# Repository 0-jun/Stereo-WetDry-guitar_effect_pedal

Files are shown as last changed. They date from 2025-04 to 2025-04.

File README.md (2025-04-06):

Stereo Wet/Dry pedal
=======================
The effect pedal has the following functions.
* Dry_In : Split dry signal to sum into each channel of the stereo wet signal
* Dry_Buffered_Bypass (DBD) : Output buffered dry signal for using input of another pedal
* Wet_Right_In (WR In), Wet_Left_In (WL In) : Stereo input for signals such as delay, reverb, chorus, etc
* WRD_Out, WLD_Out : Output stereo of wet+dry signal (or you can use it as a mono using only one channel)
* Four volume knob : Set the volume of two dry signals and two wet signals by knob

## PCB
I divided the pcb into three to put all parts in the pedal case.
1. power part
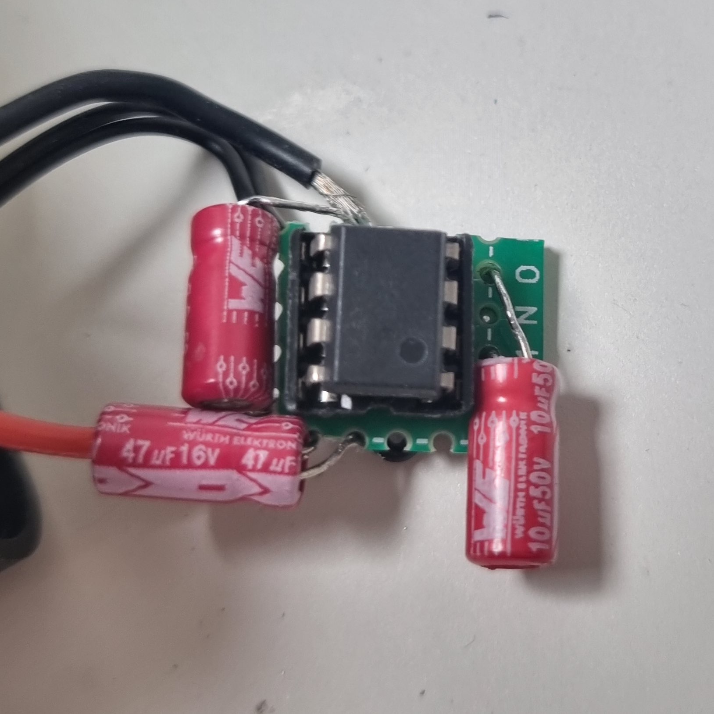
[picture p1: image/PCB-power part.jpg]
PCB-power part

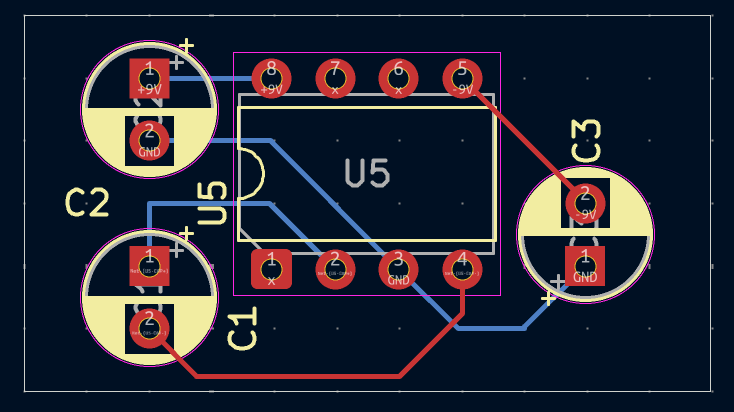
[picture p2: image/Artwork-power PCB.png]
Artwork-power part

2. register for half vdd inputa
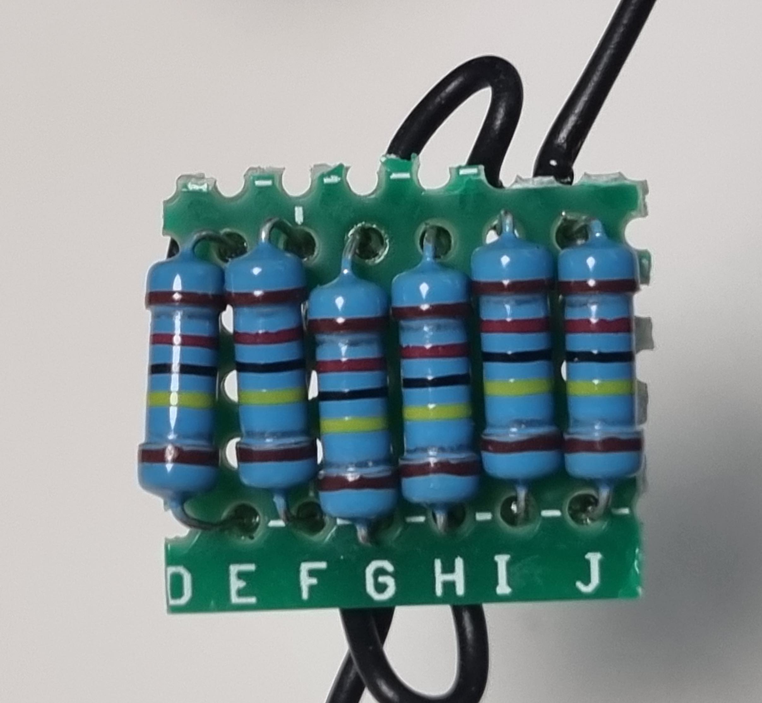
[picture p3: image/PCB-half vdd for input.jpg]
PCB-half vdd for input part

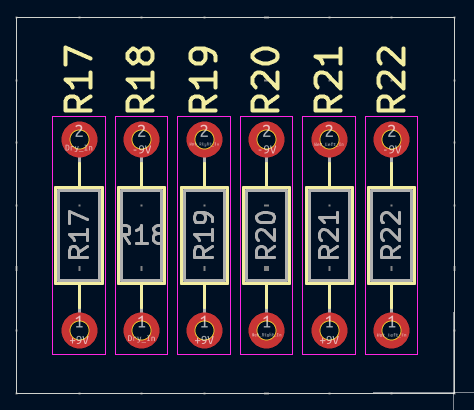
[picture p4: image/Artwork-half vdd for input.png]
Artwork-half vdd for input part

3. main part (opamp)
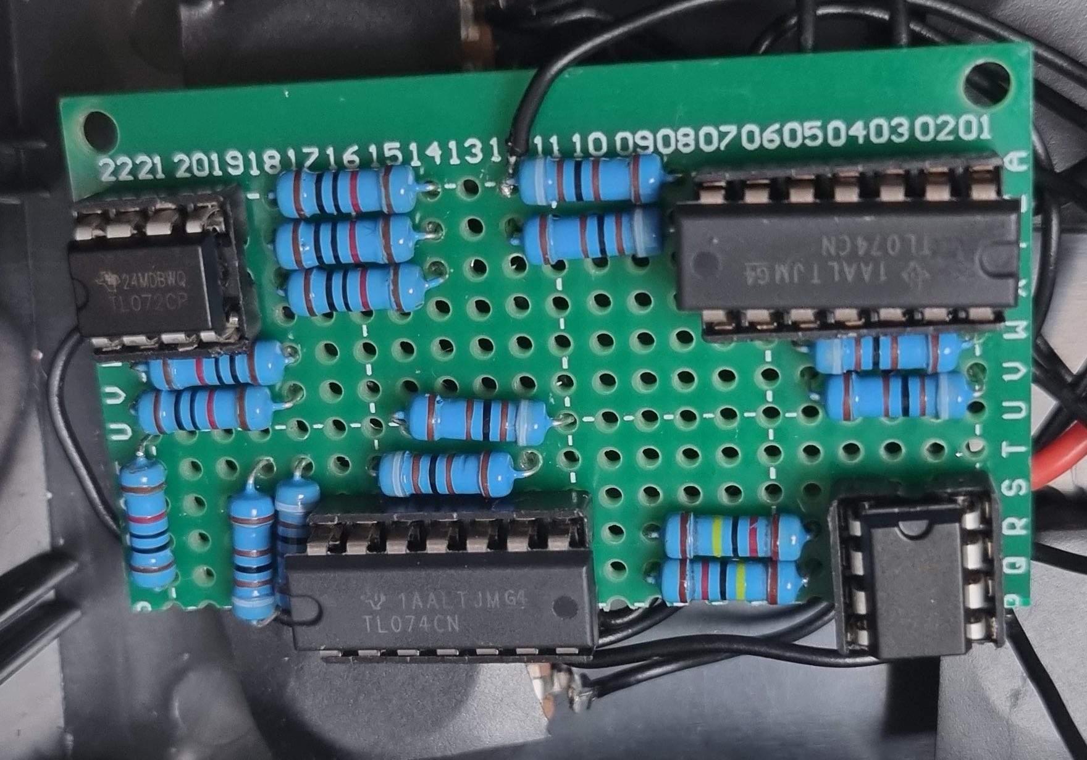
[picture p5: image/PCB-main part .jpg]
PCB-main part

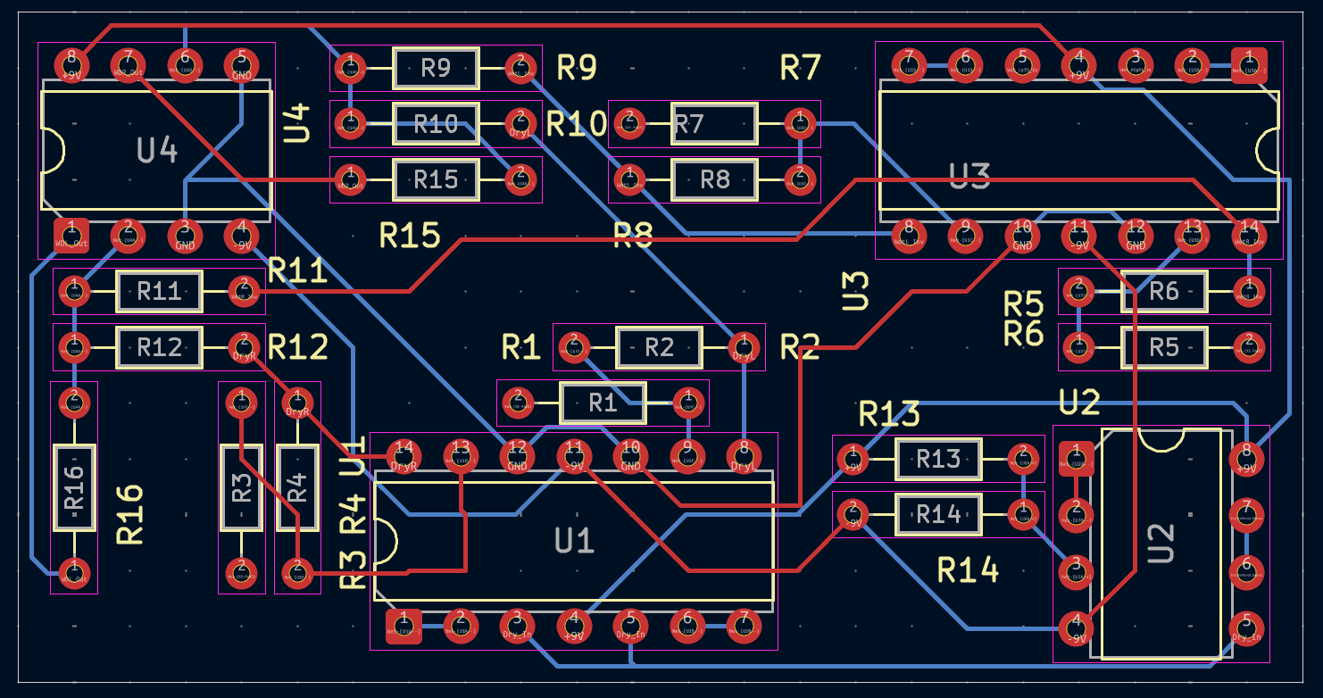
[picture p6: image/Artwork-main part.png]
Artwork-main part


## Verify signal
1.Verify Dry_In (triangle wave) signal and Dry_Buffered_Bypass
 * blue signal : Dry_In (STM32 DAC out (triangle wave))
 * yellow signal : Dry_Buffered_Bypass
Dry_In and Dry_Buffered_Bypass
2. Verify Dry_In signal (triangle wave) and WRD_Out signal (guitar signal) mixed
 * blue signal : Dry_In (STM32 DAC out (triangle wave))
 * yellow signal : WRD_Out (blue signal + guitar signal)
Mixed signal

## Conclusion
It was confirmed that the dry signal and the wet signal were mixed when connected in the following configuration.\
Also, it can be used channel2 of U2(OPAMP) for Dry_Buffered_Byass2.

### configuration
* config1
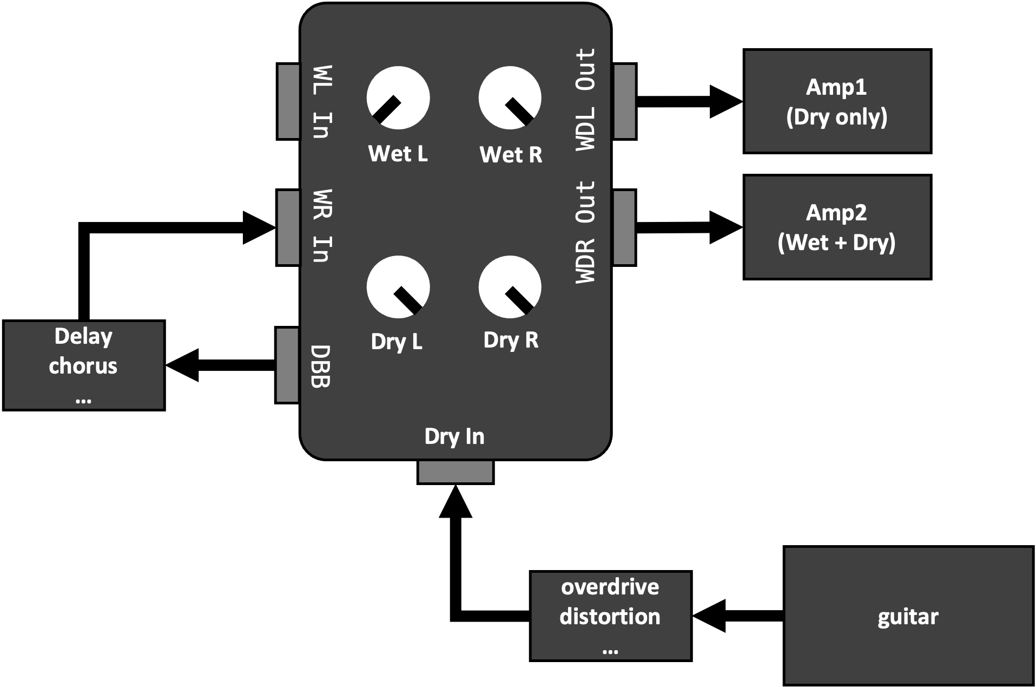
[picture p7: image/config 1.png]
config1

* config2
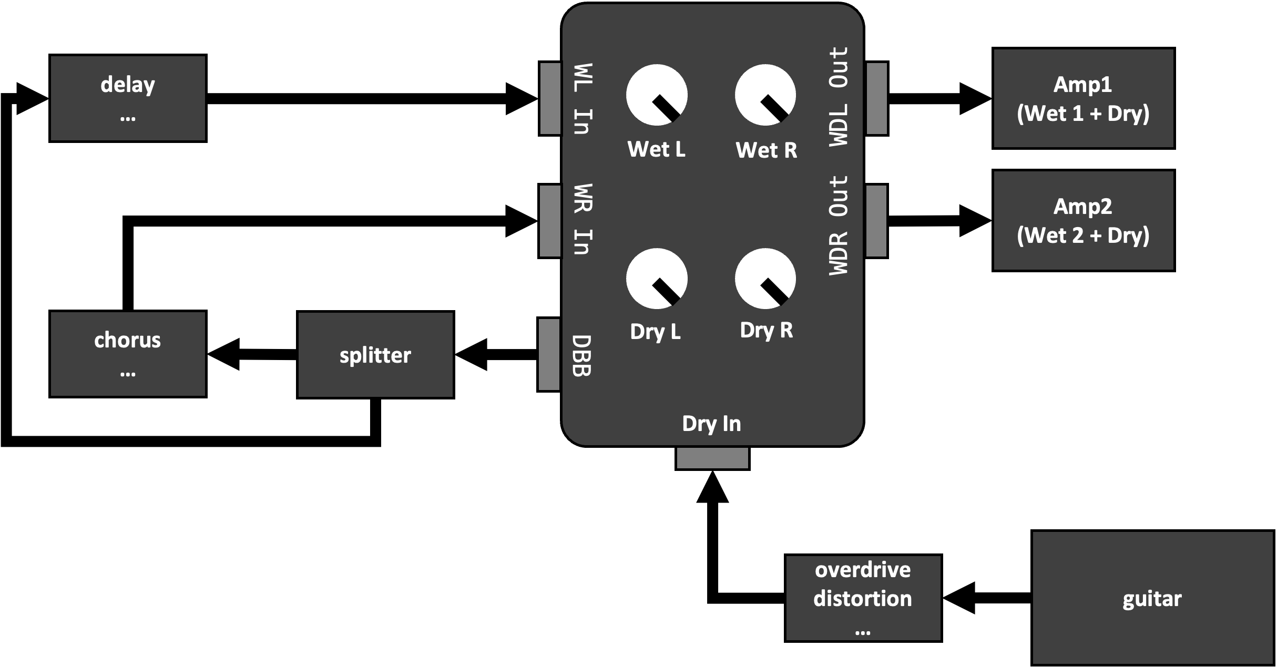
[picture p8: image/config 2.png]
config2

* config3
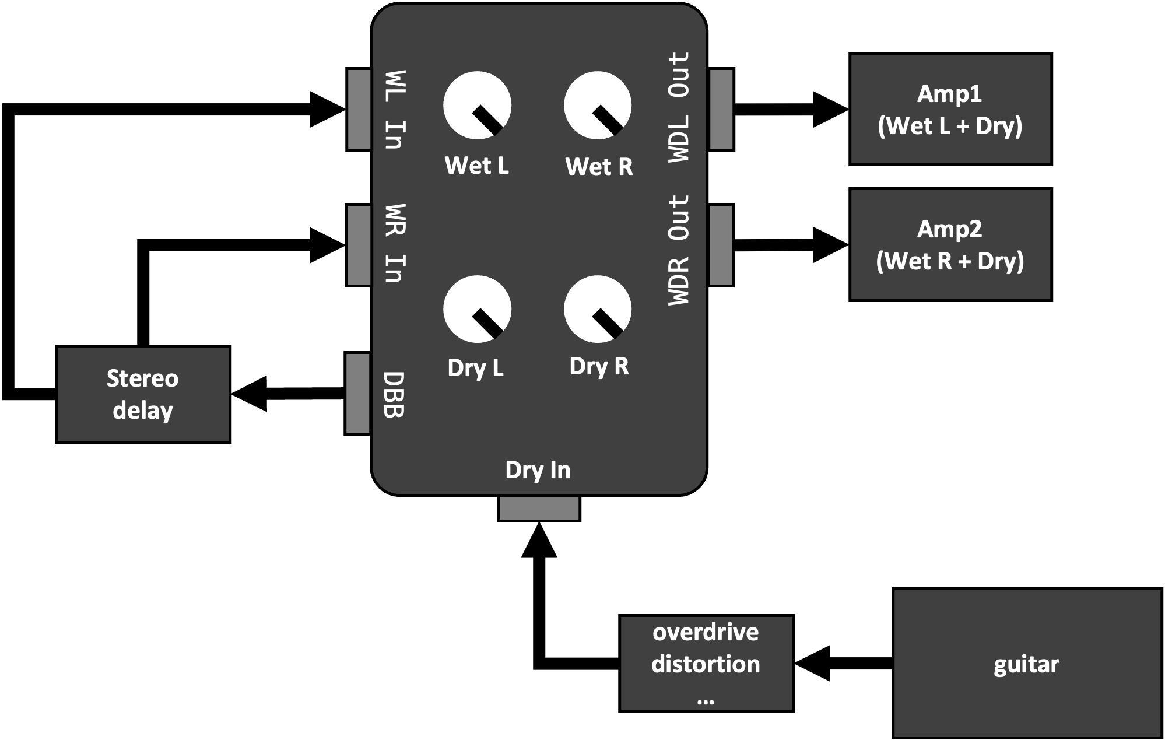
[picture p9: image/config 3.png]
config3


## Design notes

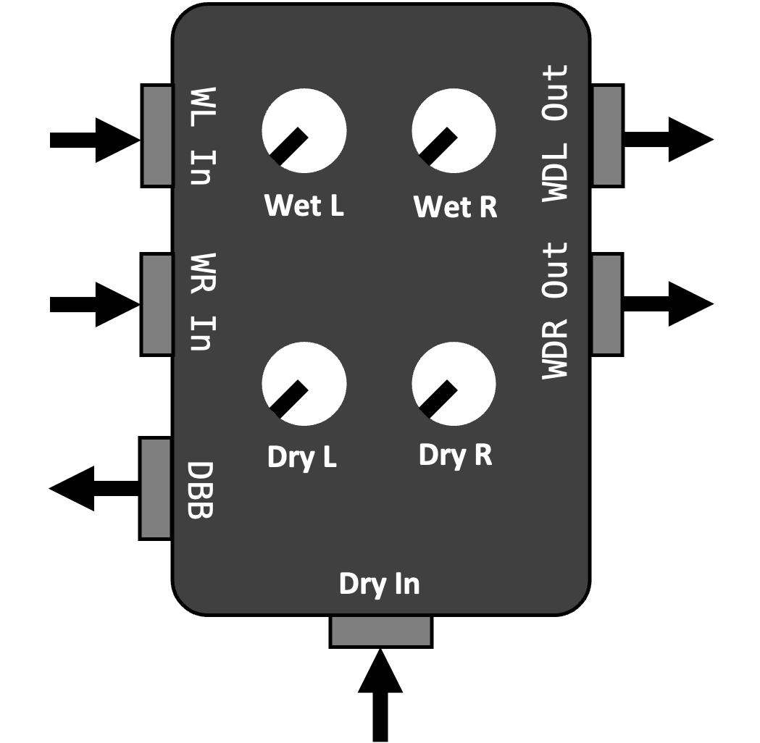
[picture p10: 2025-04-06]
image/pedal.png

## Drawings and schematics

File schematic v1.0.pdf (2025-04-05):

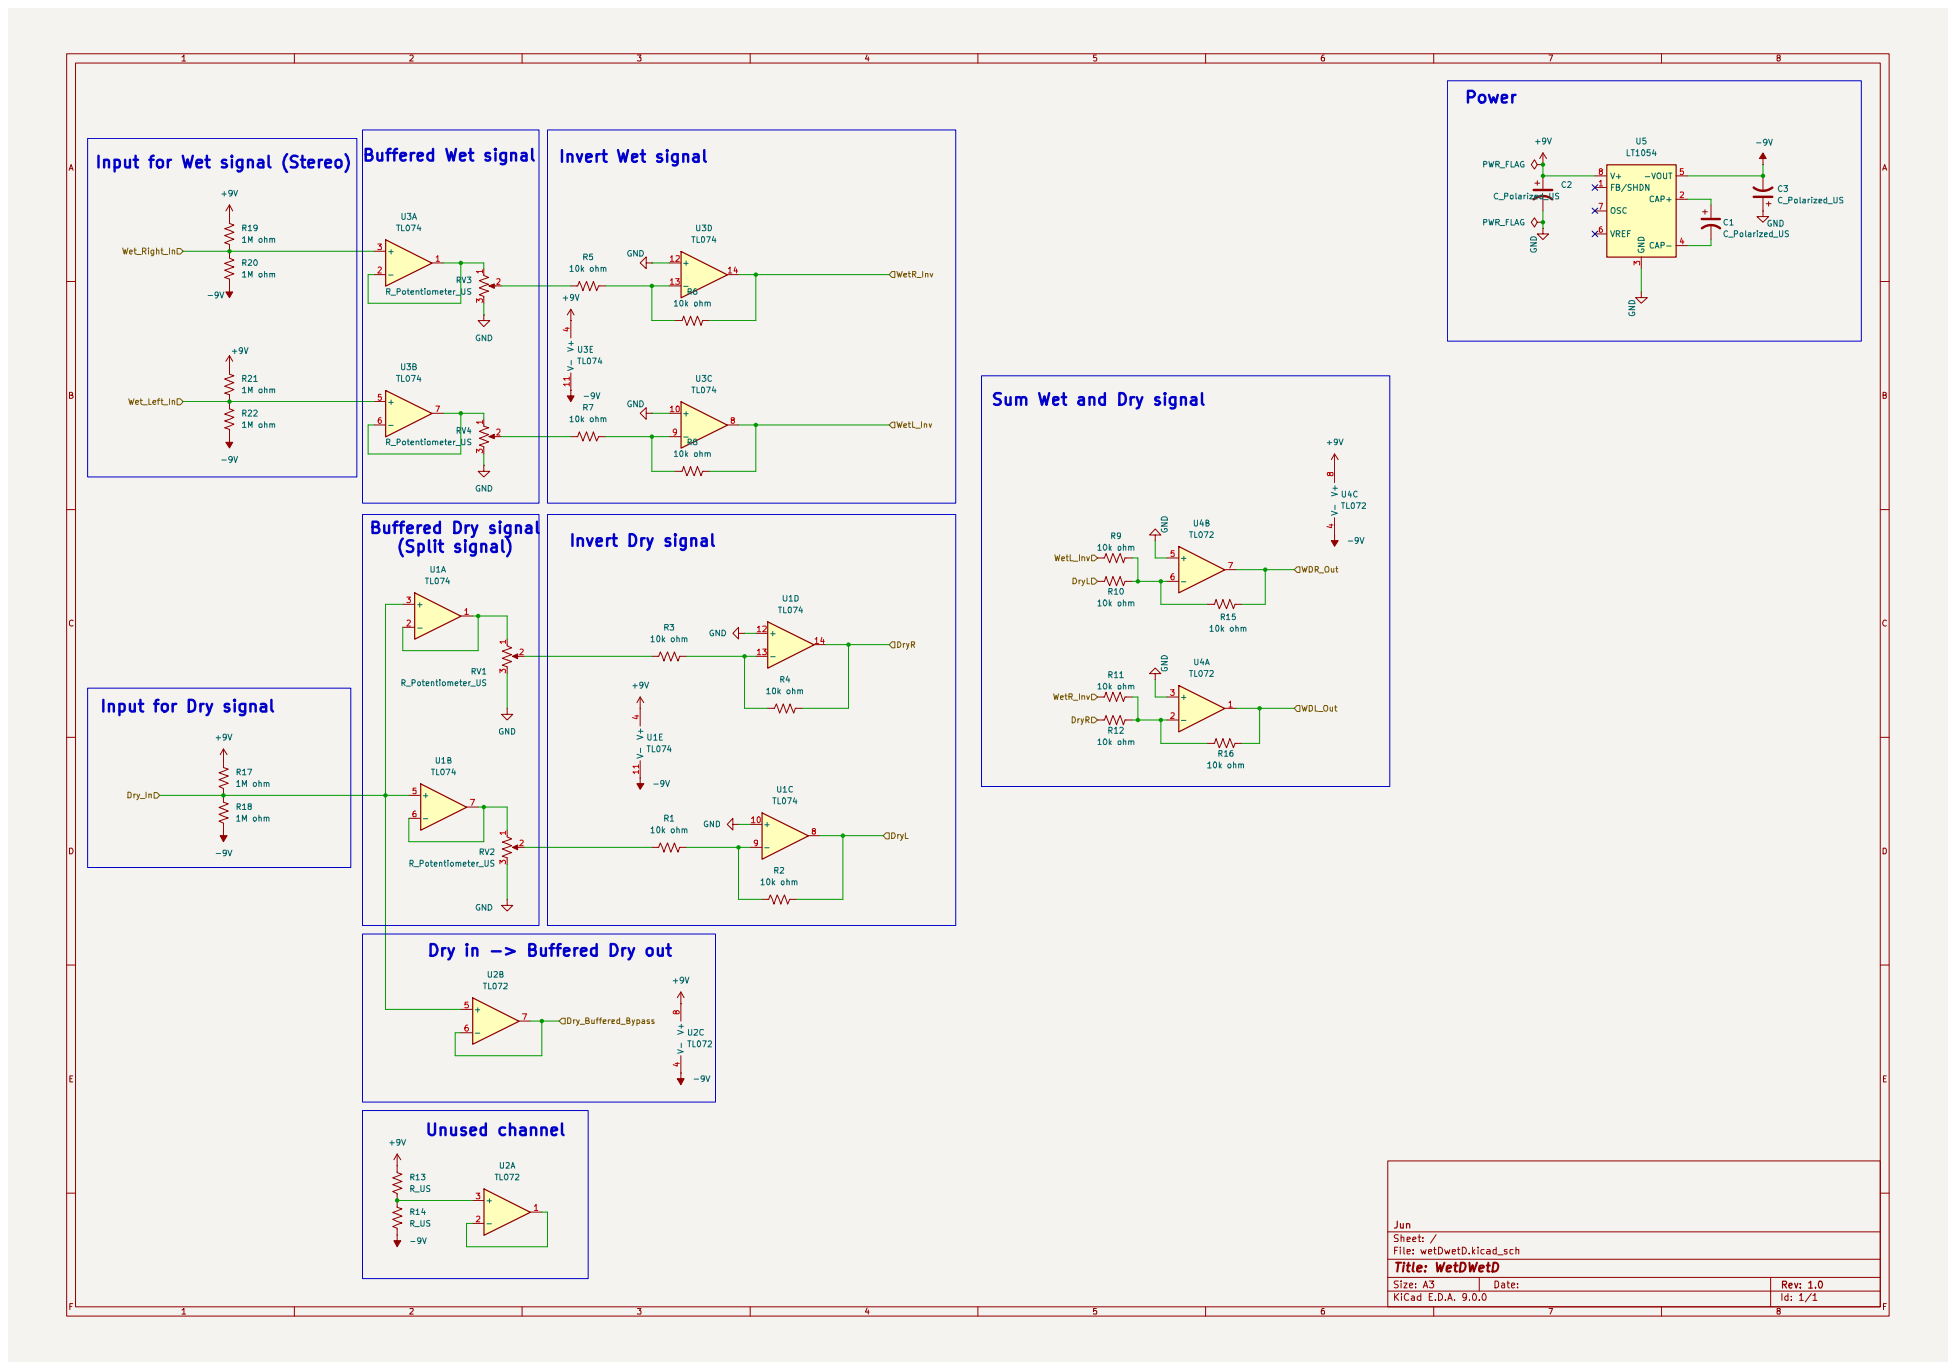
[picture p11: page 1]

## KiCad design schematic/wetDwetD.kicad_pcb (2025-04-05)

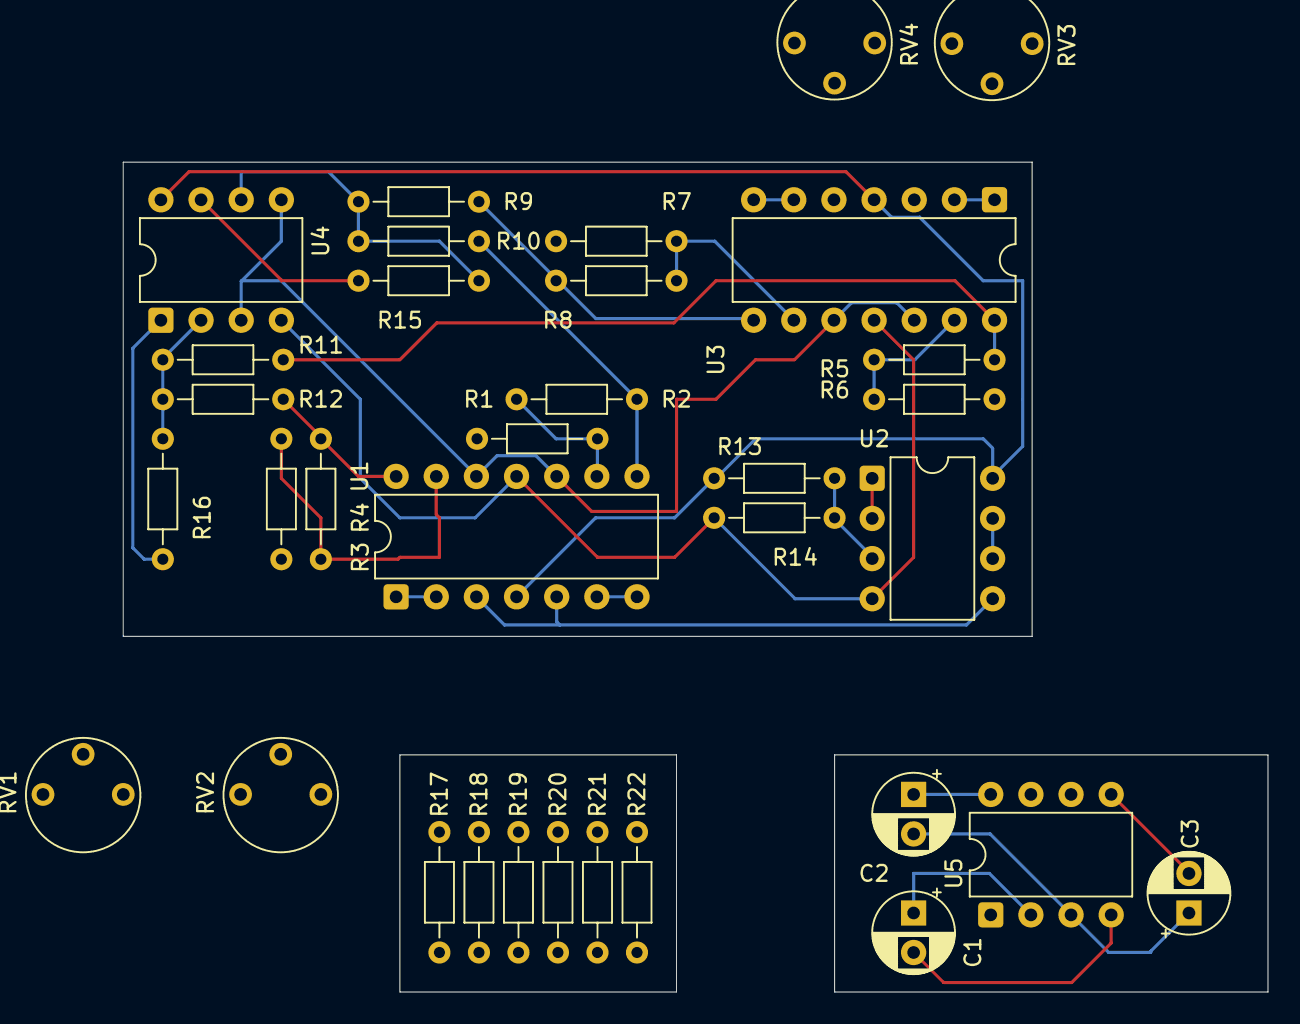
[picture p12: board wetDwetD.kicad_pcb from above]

Board: 2 copper layers, 72.4 x 52.5 mm, 34 parts (0 on the bottom side), 31 nets.

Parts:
C1, C2, C3: C_Polarized_US; CP_Radial_D5.0mm_P2.50mm
R1, R2, R3, R4, R5, R6, R7, R8, R9, R10, R11, R12, R15, R16: 10k ohm; R_Axial_DIN0204_L3.6mm_D1.6mm_P7.62mm_Horizontal
R13, R14: R_US; R_Axial_DIN0204_L3.6mm_D1.6mm_P7.62mm_Horizontal
R17, R18, R19, R20, R21, R22: 1M ohm; R_Axial_DIN0204_L3.6mm_D1.6mm_P7.62mm_Horizontal
RV1, RV2, RV3, RV4: R_Potentiometer_US; Potentiometer_Vishay_T7-YA_Single_Vertical
U1, U3: TL074; DIP-14_W7.62mm
U2, U4: TL072; DIP-8_W7.62mm
U5: LT1054; DIP-8_W7.62mm

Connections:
+9V: C2.1, R13.1, R17.1, R19.1, R21.1, U1.4 (V+), U2.8 (V+), U3.4 (V+), U4.8 (V+), U5.8 (V+)
-9V: C3.2, R14.2, R18.2, R20.2, R22.2, U1.11 (V-), U2.4 (V-), U3.11 (V-), U4.4 (V-), U5.5 (-VOUT)
/DryL: R2.1, R10.2, U1.8
/DryR: R4.1, R12.2, U1.14
/Dry_Buffered_Bypass: U2.6 (-), U2.7
/Dry_In: R17.2, R18.1, U1.3 (+), U1.5 (+), U2.5 (+)
/WDL_Out: R16.1, U4.1
/WDR_Out: R15.1, U4.7
/WetL_Inv: R8.1, R9.2, U3.8
/WetR_Inv: R6.1, R11.2, U3.14
/Wet_Left_In: R21.2, R22.1, U3.5 (+)
/Wet_Right_In: R19.2, R20.1, U3.3 (+)
GND: C2.2, C3.1, RV1.3, RV2.3, RV3.3, RV4.3, U1.10 (+), U1.12 (+), U3.10 (+), U3.12 (+), U4.3 (+), U4.5 (+), U5.3 (GND)
unnamed: R1.2, RV2.2
unnamed: R3.2, RV1.2
unnamed: R5.2, RV3.2
unnamed: R7.2, RV4.2
unnamed: RV1.1, U1.1, U1.2 (-)
unnamed: RV2.1, U1.6 (-), U1.7
unnamed: R1.1, R2.2, U1.9 (-)
unnamed: R3.1, R4.2, U1.13 (-)
unnamed: R13.2, R14.1, U2.3 (+)
unnamed: U2.1, U2.2 (-)
unnamed: RV3.1, U3.1, U3.2 (-)
unnamed: RV4.1, U3.6 (-), U3.7
unnamed: R7.1, R8.2, U3.9 (-)
unnamed: R5.1, R6.2, U3.13 (-)
unnamed: R11.1, R12.1, R16.2, U4.2 (-)
unnamed: R9.1, R10.1, R15.2, U4.6 (-)
unnamed: C1.1, U5.2 (CAP+)
unnamed: C1.2, U5.4 (CAP-)

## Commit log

2025-04-06 Add pedal chain image
2025-04-06 Add PCB image
2025-04-06 Modify main part pcb (rotate)
2025-04-06 Rename PCB-main part.jpg to PCB-main part .jpg
